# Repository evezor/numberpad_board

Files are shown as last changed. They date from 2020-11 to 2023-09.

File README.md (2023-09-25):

# Numberpad Board
*please note this board has been deprecated.

An edge board containing with a numberpad face with 12 buttons. 

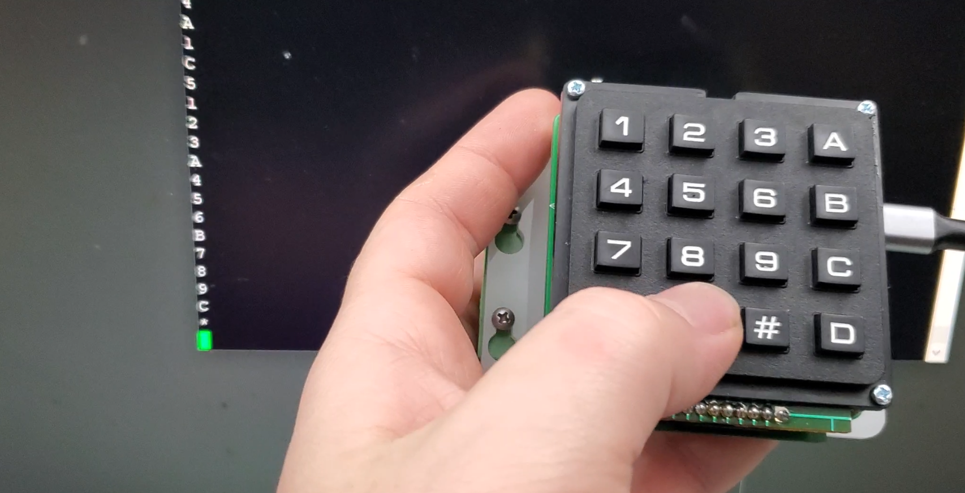
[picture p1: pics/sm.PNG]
sm


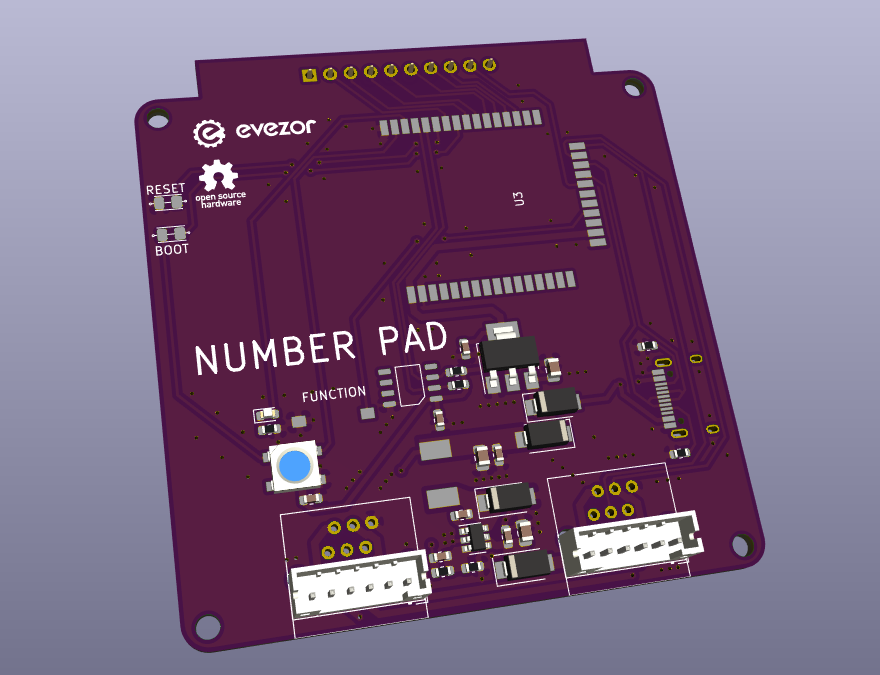
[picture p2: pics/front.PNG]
front


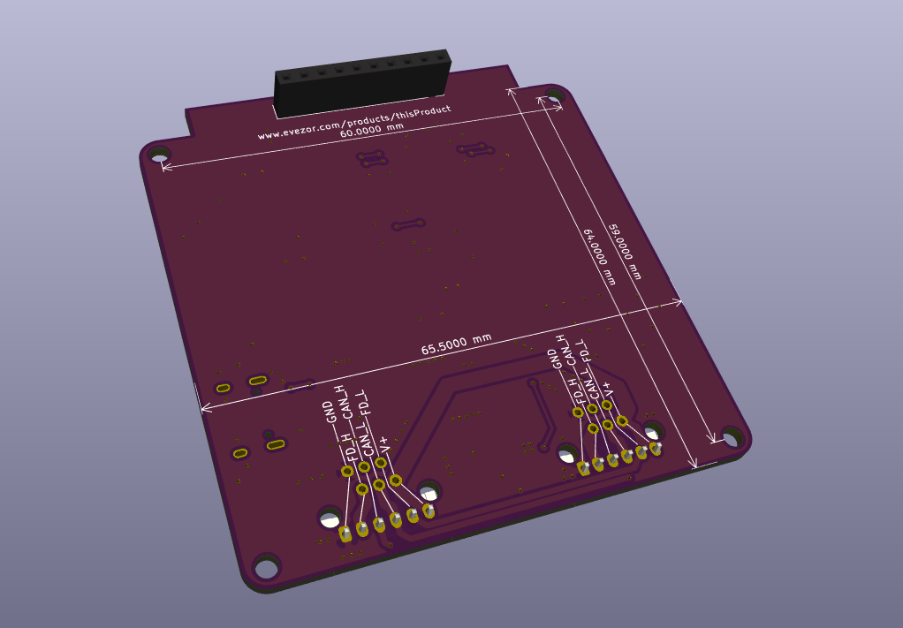
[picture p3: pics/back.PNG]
back


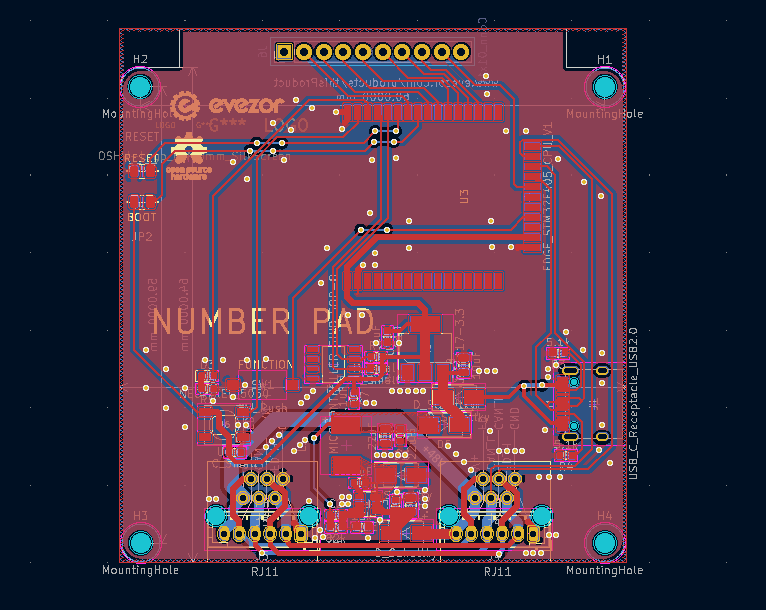
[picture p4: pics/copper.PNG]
copper


sch

source files can be found here: hhttps://github.com/evezor/v0_numberpad_board

This board uses the Evezor Stamp STMF405 MCU

source: https://github.com/evezor/Evezor-Stamp-STMF405

Evezor® and all associated marks, logos, and designs are registered trademarks and protected by copyright. Unauthorized use or reproduction of these trademarks and copyrighted materials is strictly prohibited.

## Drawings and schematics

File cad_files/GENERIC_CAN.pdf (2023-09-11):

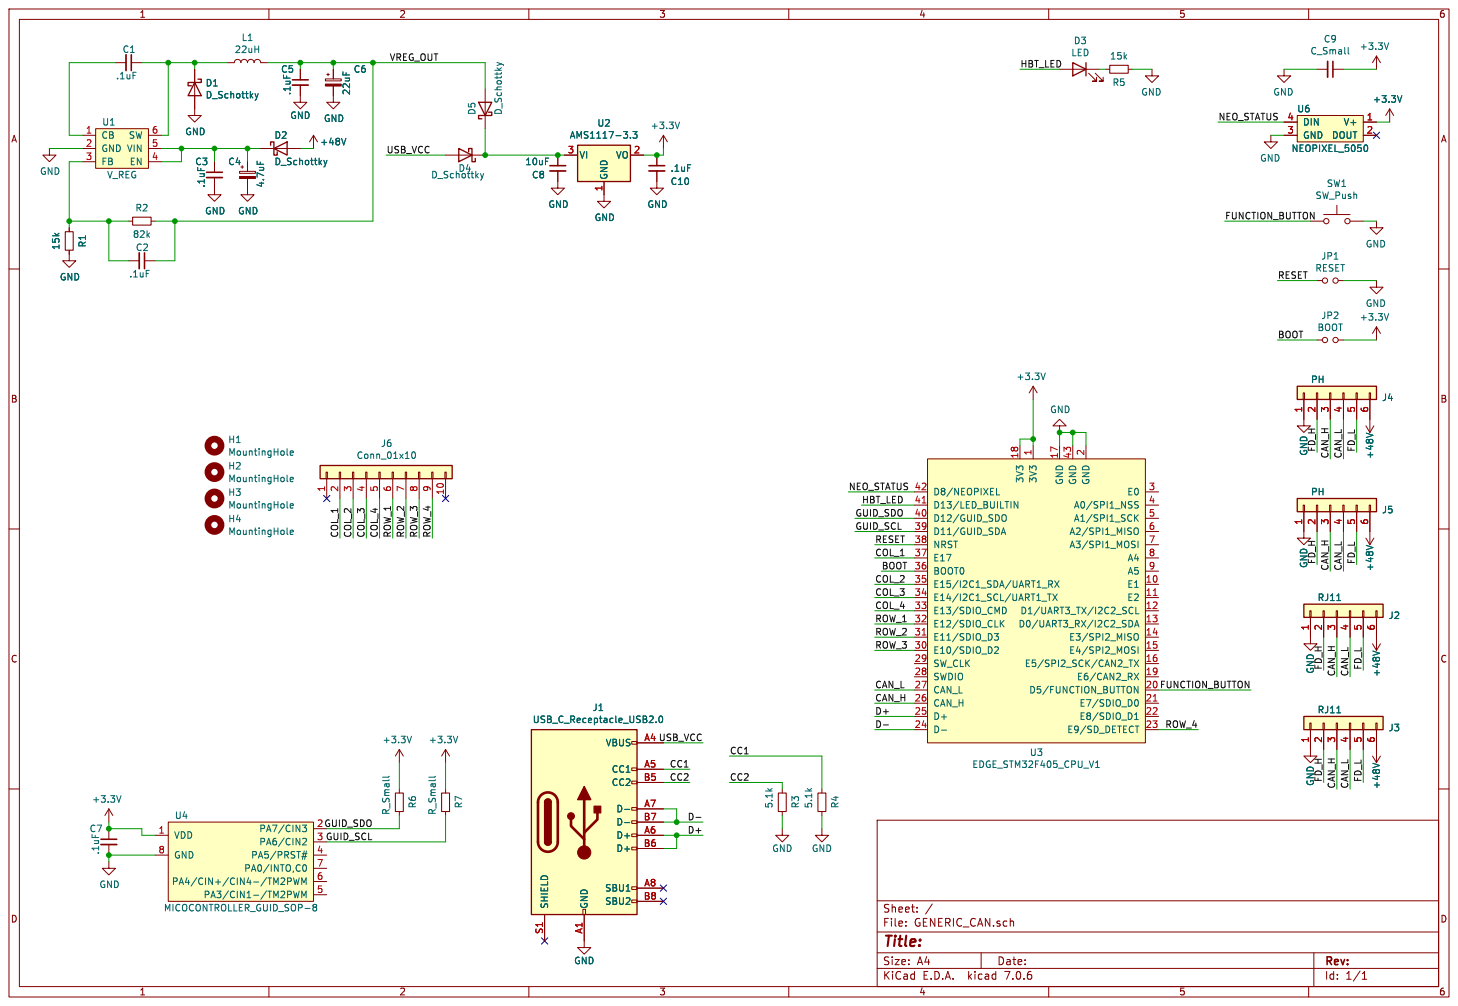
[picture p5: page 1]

6 +48V U6 NEOPIXEL_5050 V+ 1 DOUT 2 GND 3 DIN 4 +3.3V GND

2 D5/FUNCTION_BUTTON 20 E7/SDIO_D0 21 E8/SDIO_D1 22 E9/SD_DETECT 23 D- 24 D+ 25 CAN_H 26 CAN_L 27 SWDIO 28 SW_CLK 29 E0 3 E10/SDIO_D2 30 E11/SDIO_D3 31 E12/SDIO_CLK 32 E13/SDIO_CMD 33 E14/I2C1_SCL/UART1_TX 34 E15/I2C1_SDA/UART1_RX 35 BOOT0 36 E17 37 NRST 38 D11/GUID_SDA 39 A0/SPI1_NSS 4 D12/GUID_SDO 40 D13/LED_BUILTIN 41 D8/NEOPIXEL 42 GND 43 A1/SPI1_SCK 5 A2/SPI1_MISO 6 A3/SPI1_MOSI 7 A4 8 A5 9 U3 EDGE_STM32F405_CPU_V1 +48V GND

Id: 1/1 Title: File: GENERIC_CAN.sch Sheet: /

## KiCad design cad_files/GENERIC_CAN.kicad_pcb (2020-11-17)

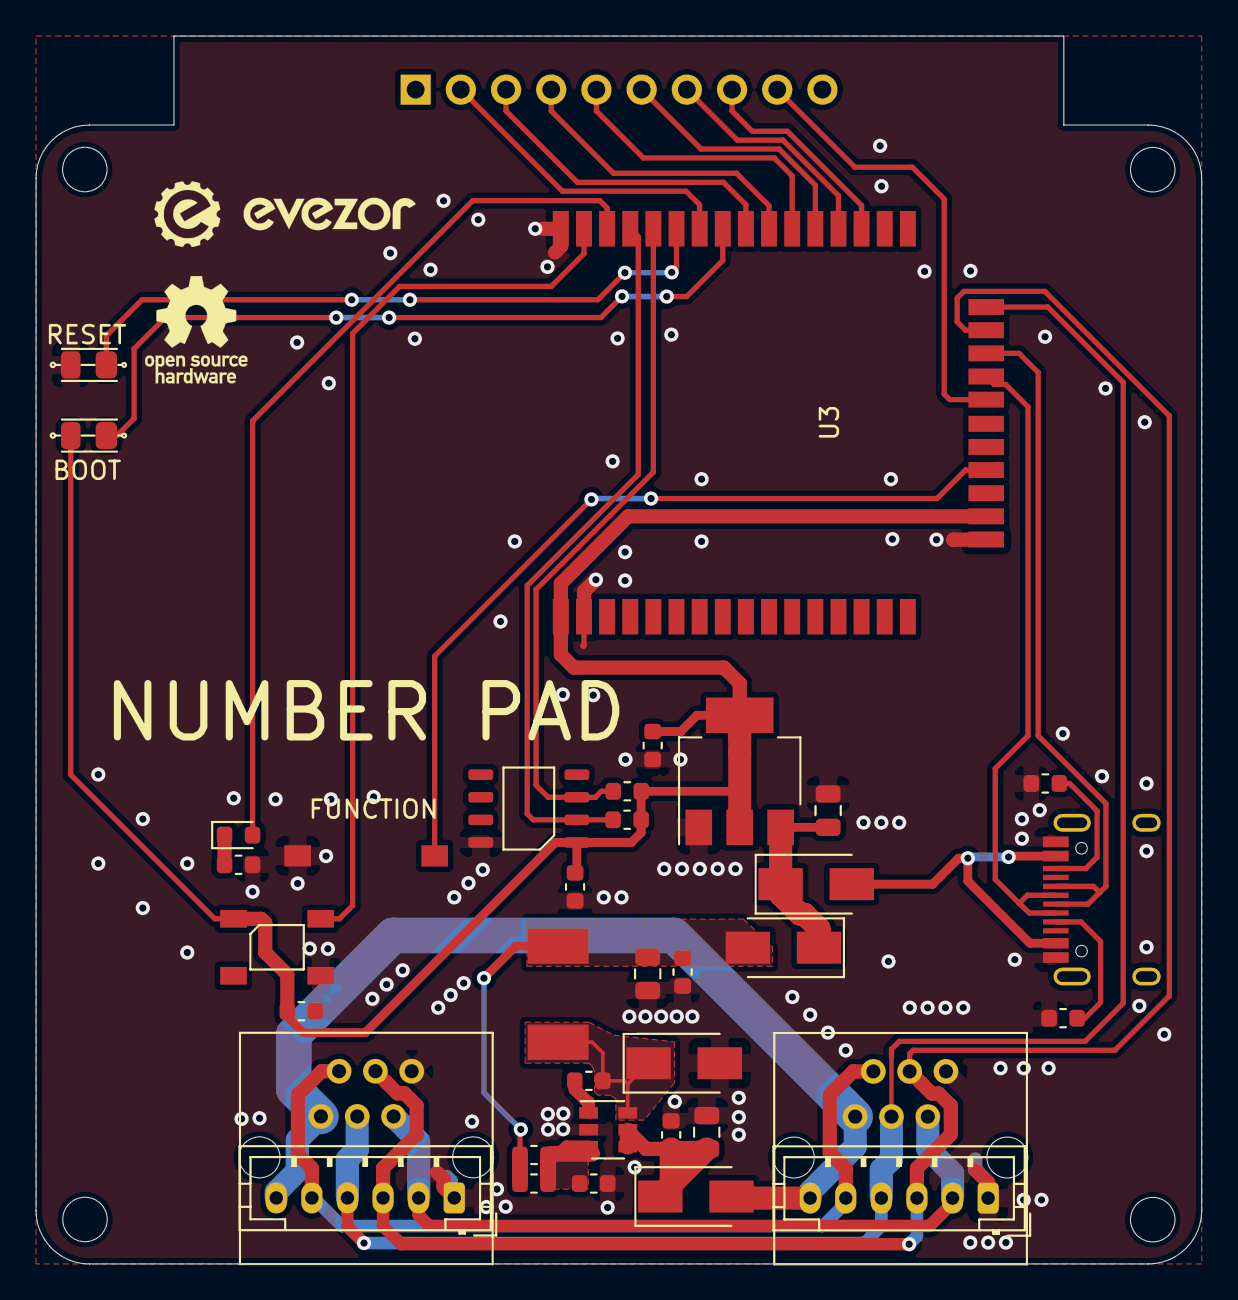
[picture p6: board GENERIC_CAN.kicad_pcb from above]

Board: 2 copper layers, 65.5 x 69.0 mm, 41 parts (1 on the bottom side), 34 nets.

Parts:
C1, C2, C3, C5, C7, C10: .1uF; C_0603_1608Metric
C4: 4.7uF; C_0805_2012Metric
C6: 22uF; C_0805_2012Metric
C8: 10uF; C_0805_2012Metric
C9: C_Small; C_0603_1608Metric
D1, D2, D4, D5: D_Schottky; D_SMA
D3: LED; LED_0603_1608Metric
H1, H2, H3, H4: MountingHole; MountingHole_2.5mm
J1: USB_C_Receptacle_USB2.0; USB_C_Receptacle_HRO_TYPE-C-31-M-12
J2, J3: RJ11; RJ11_C189747_Horizontal
J4, J5: PH; JST_PH_B6B-PH-K_1x06_P2.00mm_Vertical
J6: Conn_01x10; PinSocket_1x10_P2.54mm_Vertical
JP1: RESET; SHORT_PAD
JP2: BOOT; SHORT_PAD
L1: 22uH; INDUCTOR_7.5X6.6_GCDA0630-220MC
R1, R5: 15k; R_0603_1608Metric
R2: 82k; R_0603_1608Metric
R3, R4: 5.1k; R_0603_1608Metric
R6, R7: R_Small; R_0603_1608Metric
SW1: SW_Push; SWITCH_2x3_SMD_TACTILE_GREEN
U1: V_REG; SOT-23-6
U2: AMS1117-3.3; SOT-223-3_TabPin2
U3: EDGE_STM32F405_CPU_V1; EDGE_STAMP
U4: MICOCONTROLLER_GUID_SOP-8; GUID_PS150C
U6: NEOPIXEL_5050

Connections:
+3V3: C7.1, C9.1, C10.1, JP2.2, R6.2, R7.2, U2.2, U3.1, U3.18, U4.1, U6.1
+48V: D2.2, J2.6, J3.6, J4.6, J5.6
/BOOT: JP2.1, U3.36
/CAN_H: J2.3, J3.3, J4.3, J5.3, U3.26
/CAN_L: J2.4, J3.4, J4.4, J5.4, U3.27
/CC1: J1.A5, R4.1
/CC2: J1.B5, R3.1
/COL_1: J6.2, U3.37
/COL_2: J6.3, U3.35
/COL_3: J6.4, U3.34
/COL_4: J6.5, U3.33
/D+: J1.A6, J1.B6, U3.25
/D-: J1.A7, J1.B7, U3.24
/FD_H: J2.2, J3.2, J4.2, J5.2
/FD_L: J2.5, J3.5, J4.5, J5.5
/FUNCTION_BUTTON: SW1.1, U3.20
/GUID_SCL: R7.1, U3.39, U4.3
/GUID_SDO: R6.1, U3.40, U4.2
/HBT_LED: D3.2, U3.41
/NEO_STATUS: U3.42, U6.4
/RESET: JP1.1, U3.38
/ROW_1: J6.6, U3.32
/ROW_2: J6.7, U3.31
/ROW_3: J6.8, U3.30
/ROW_4: J6.9, U3.23
/USB_VCC: D4.2, J1.A4, J1.A9, J1.B4, J1.B9
/VREG_OUT: C2.1, C5.1, C6.1, D5.2, L1.2, R2.1
GND: C3.2, C4.2, C5.2, C6.2, C7.2, C8.2, C9.2, C10.2, D1.2, J1.A1, J1.A12, J1.B1, J1.B12, J2.1, J3.1, J4.1, J5.1, JP1.2, R1.1, R3.2, R4.2, R5.1, SW1.2, U1.2, U2.1, U3.2, U3.17, U3.43, U4.8, U6.3
unnamed: C1.1, D1.1, L1.1, U1.6
unnamed: C1.2, U1.1
unnamed: C2.2, R1.2, R2.2, U1.3
unnamed: C3.1, C4.1, D2.1, U1.4, U1.5
unnamed: C8.1, D4.1, D5.1, U2.3
unnamed: D3.1, R5.2

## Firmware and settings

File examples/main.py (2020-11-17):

#test devboard code

from machine import Pin
from pyb import CAN
import utime

print("initializing")
can = CAN(1, CAN.LOOPBACK)
can.setfilter(0, CAN.LIST16, 0, (123, 124, 125, 126))


#Setup Pins
hbt_led = Pin("D13", Pin.OUT)
func_butt = Pin("D5", Pin.IN, Pin.PULL_UP) 
can_wakeup = Pin("D6", Pin.OUT)
can_wakeup.value(0)

keys = [
        ['1', '2', '3', 'A'],
        ['4', '5', '6', 'B'],
        ['7', '8', '9', 'C'],
        ['*', '0', '#', 'D'],
        ]
for i in range(4):
    for j in range(4):
        print(keys[i][j])
        
COLUMN = ["E17", "E15", "E14", "E13"]
ROW = ["E12", "E11", "E10", "SD_DETECT"]        

for i in range(len(ROW)):
    ROW[i] = Pin(ROW[i], Pin.OUT)
    ROW[i].value(0)
    
for i in range(len(COLUMN)):
    COLUMN[i] = Pin(COLUMN[i], Pin.IN, Pin.PULL_DOWN)

#Setup hbt timer
hbt_state = 0
hbt_interval = 500
start = utime.ticks_ms()
next_hbt = utime.ticks_add(start, hbt_interval)
hbt_led.value(hbt_state)



print("starting")

def chk_hbt():
    global next_hbt
    global hbt_state
    now = utime.ticks_ms()
    if utime.ticks_diff(next_hbt, now) <= 0:
        if hbt_state == 1:
            hbt_state = 0
            hbt_led.value(hbt_state)
        else:
            hbt_state = 1
            hbt_led.value(hbt_state)  
        
        next_hbt = utime.ticks_add(next_hbt, hbt_interval)

def chk_buttons():
    global next_button_chk
    now = utime_ms()
    if utime.ticks_diff(next_button_chk, now) <= 0:
        pass
        

def send():
    can.send('EVZRTST', 123)   # send a message with id 123
    
def get():
    mess = can.recv(0)
    print(mess)
        

      
      
while True:
    chk_hbt()
    
    if not (func_butt.value()):
        print("function button")
        utime.sleep_ms(200)
    
    for i in  range(len(ROW)):
        ROW[i].value(1)
        for j in range(len(COLUMN)):
            if (COLUMN[j].value()):
                print(keys[i][j])
                utime.sleep_ms(200)
        ROW[i].value(0)

    
   
